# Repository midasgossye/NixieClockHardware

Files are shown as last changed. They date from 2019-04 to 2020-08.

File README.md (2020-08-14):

# NixieClockHardware
6 digit RPi powered Nixie Clock Hardware repository

Software/source code can be found in the following repository: https://github.com/midasgossye/NixieClock/

If you are interested in a having this unique Nixie Clock, but don't want to build it from scratch, we sell these at our tindie store!


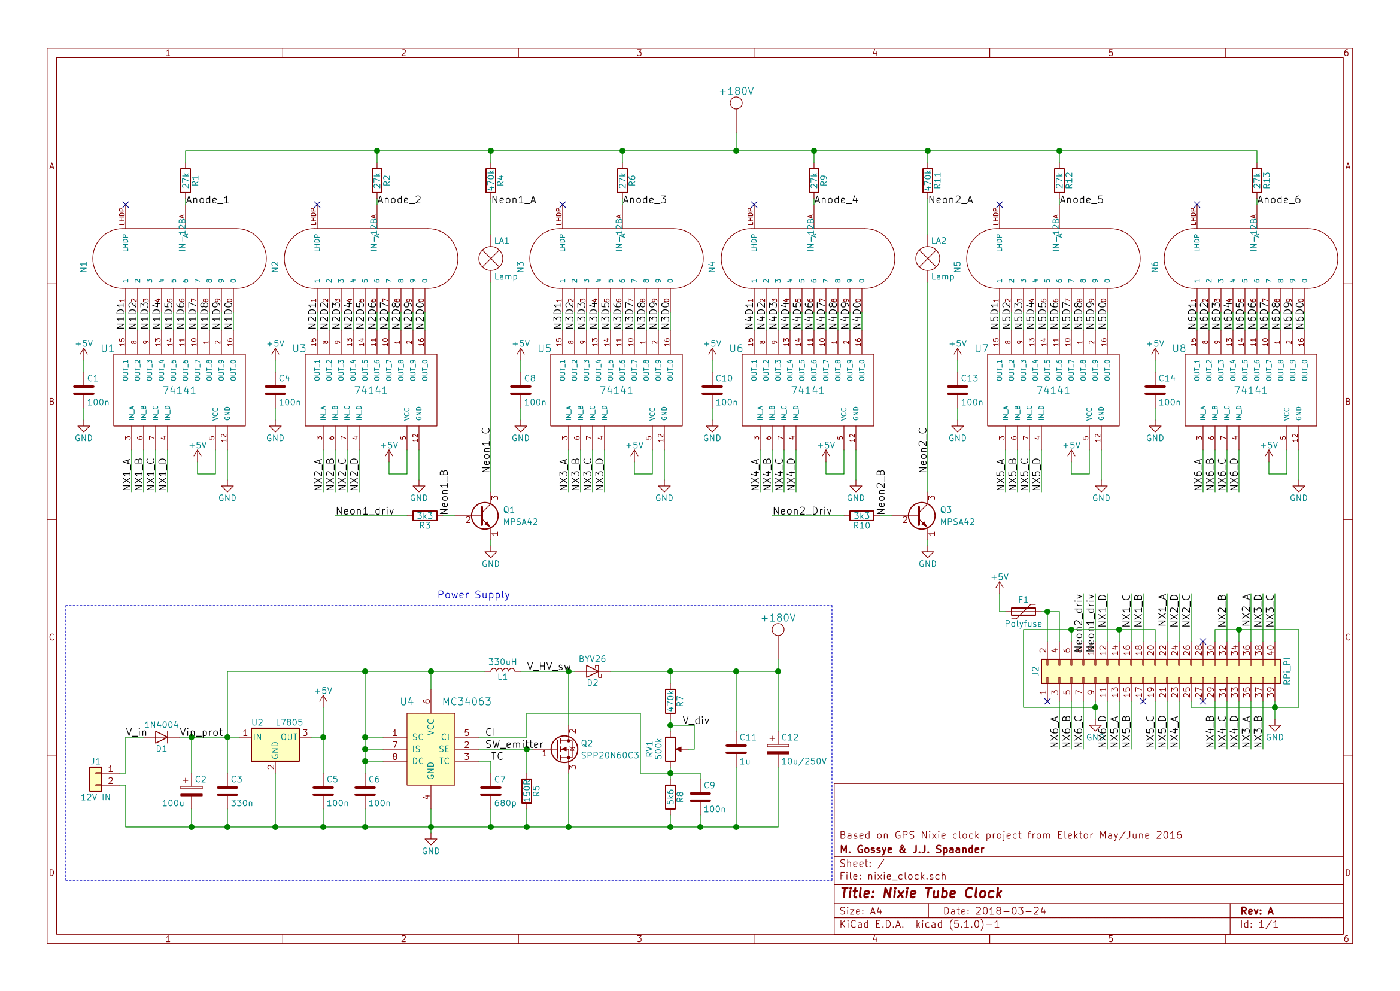
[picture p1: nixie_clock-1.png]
Schematic

Nixie picture

## Authors

* **Midas Gossye** - [Github](https://github.com/midasgossye)
* **Joshua Spaander** - [Github](https://github.com/joshuaspaander)

## Acknowledgments

* This project was inspired by and partly based on the New Precise Nixie Clock from the May 2016 issue of Elektor Magazine [(link)](https://www.elektormagazine.com/magazine/elektor-201605/28960)
* IoT connectivity inspired by EEVBlog Nixie Tube Display Project [(link)](https://www.youtube.com/playlist?list=PLvOlSehNtuHutdg1kZkG7aAYhjoJnk2fc)

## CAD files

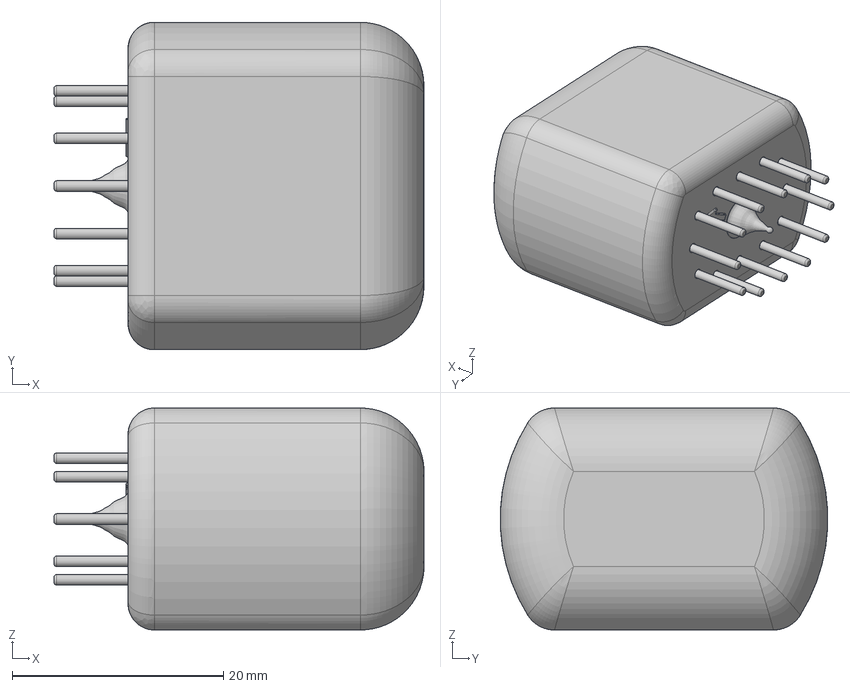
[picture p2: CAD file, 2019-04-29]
IN-12A.stp
35.0 x 31.0 x 21.0 mm

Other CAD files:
nixie_clock.wrl.sldprt
nixie_clock.wrl_0.sldprt

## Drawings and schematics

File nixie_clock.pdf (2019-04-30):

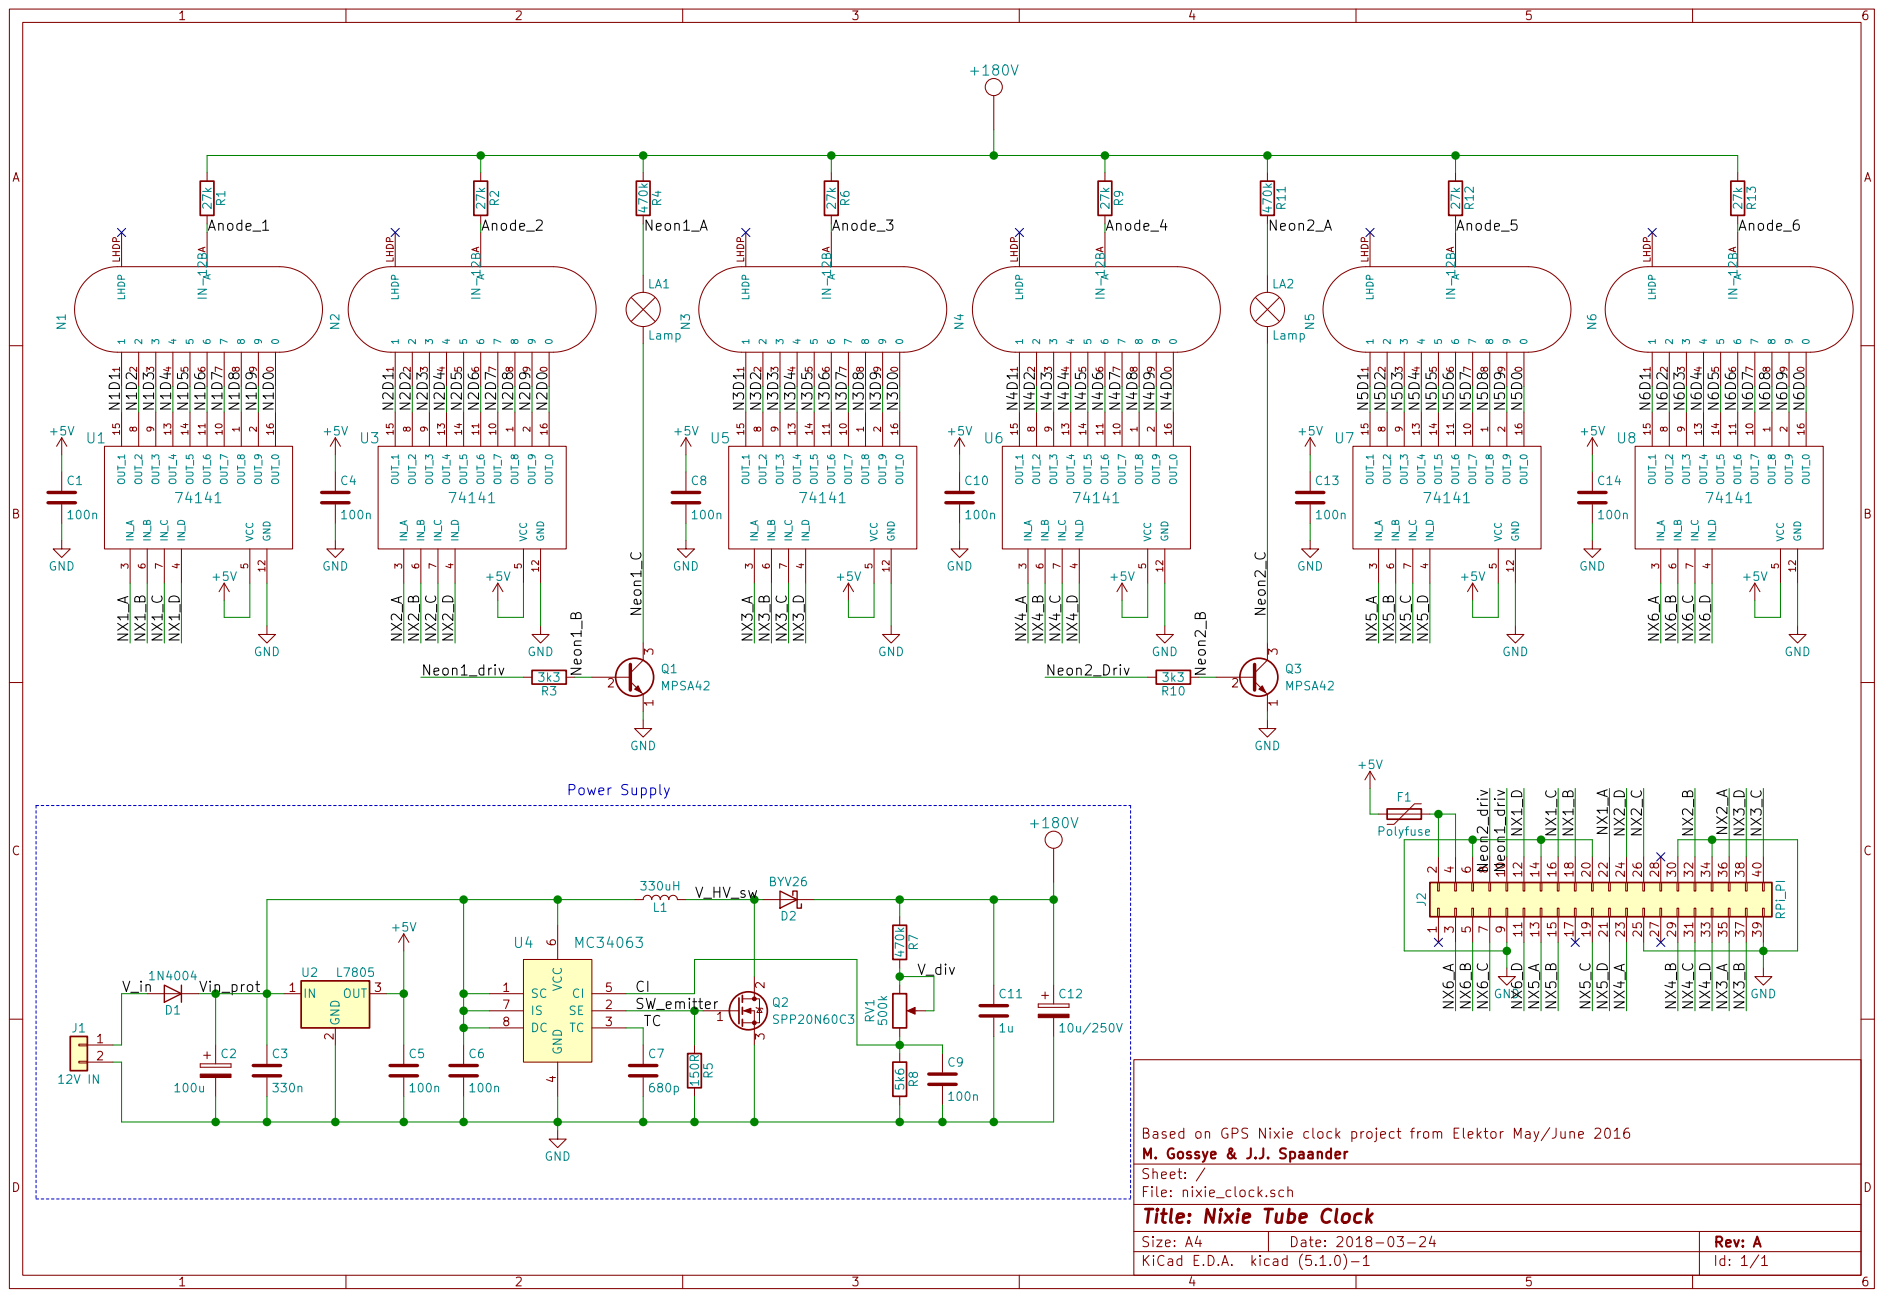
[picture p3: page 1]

Based on GPS Nixie clock project from Elektor May/June 2016
File: nixie_clock.sch Sheet: / M. Gossye & J.J. Spaander

Id: 1/1 Title: Nixie Tube Clock

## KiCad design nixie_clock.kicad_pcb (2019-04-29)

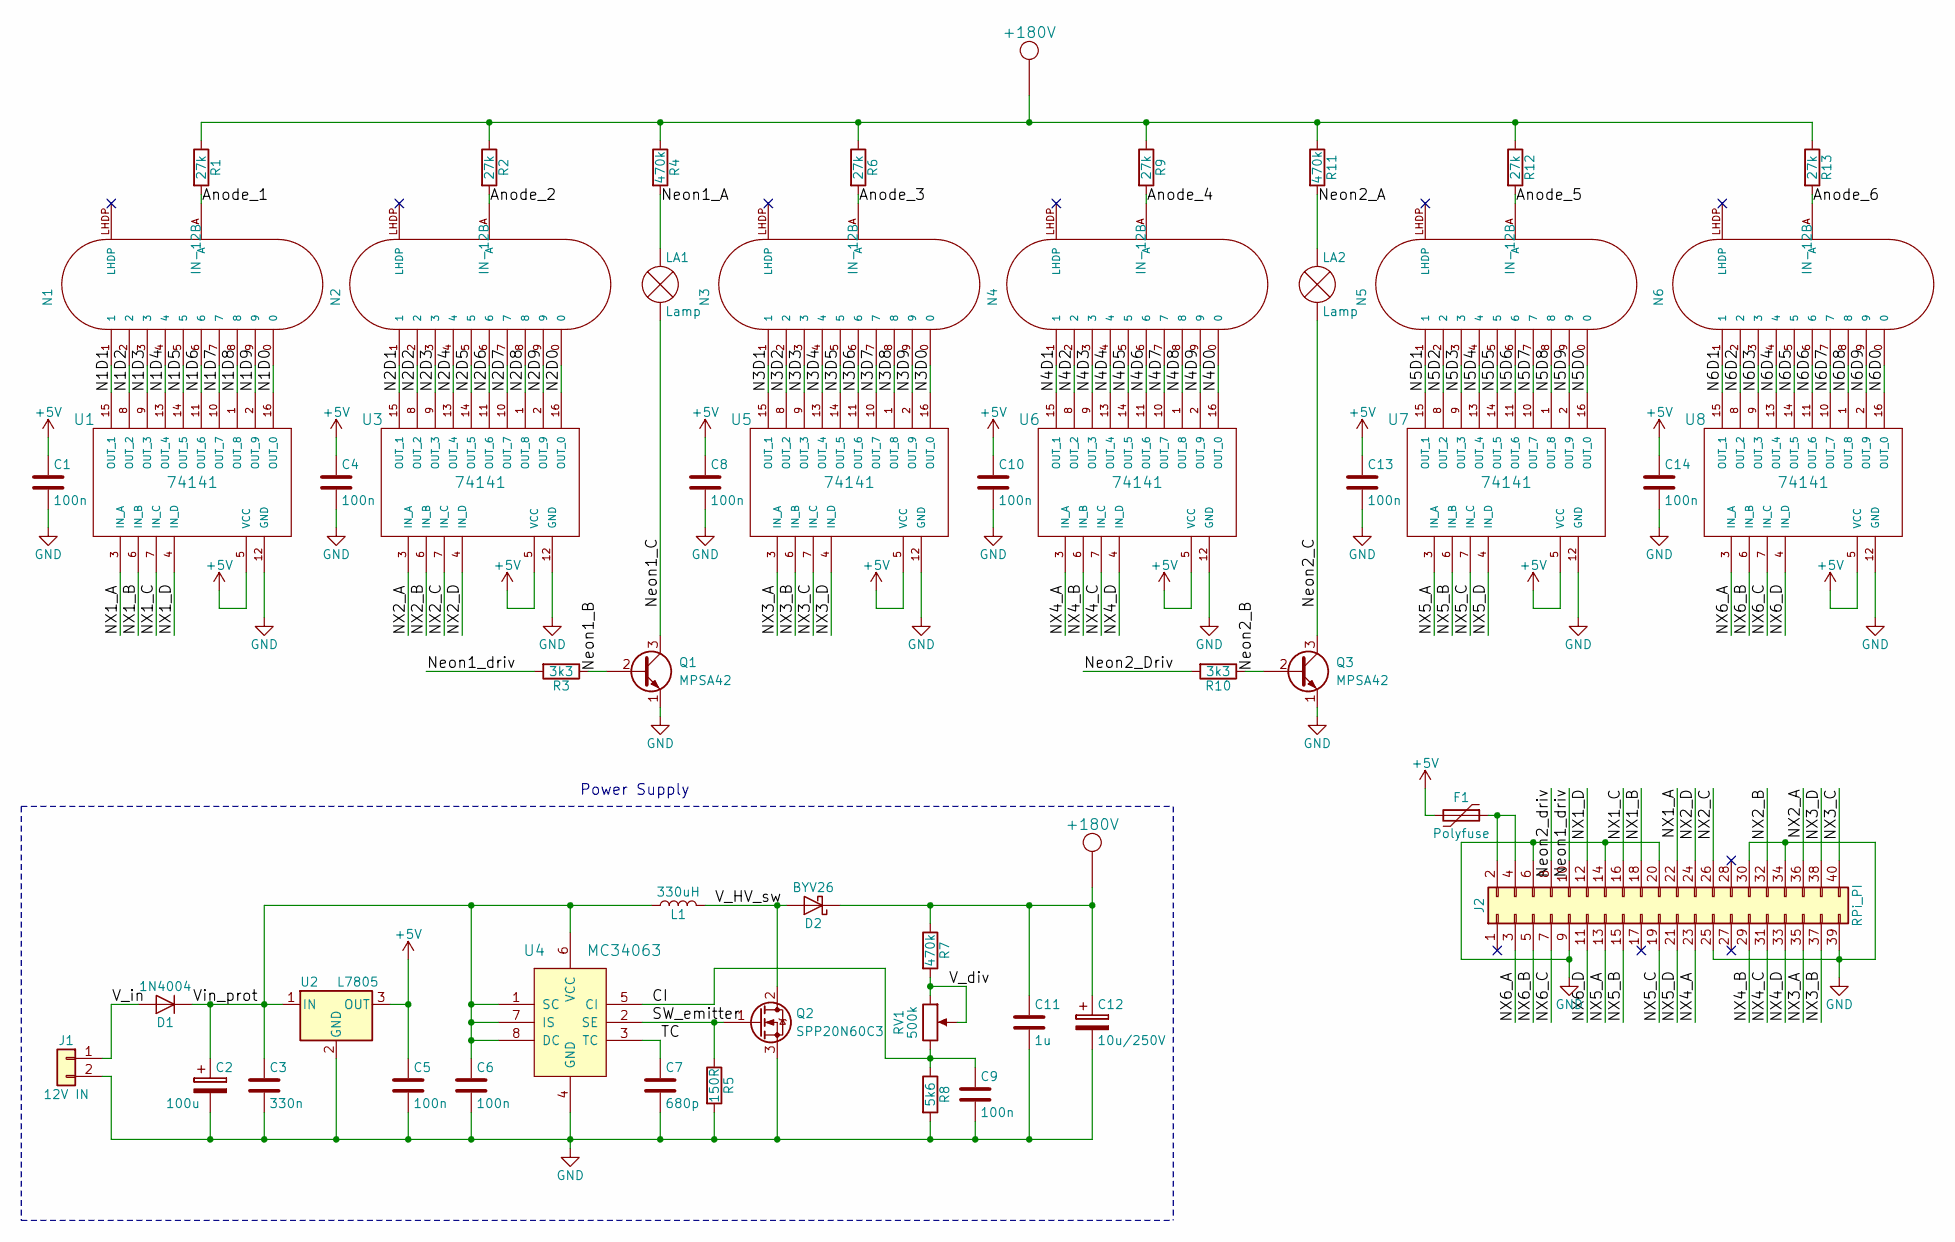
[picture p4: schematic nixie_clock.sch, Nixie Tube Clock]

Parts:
C1, C4, C5, C6, C8, C9, C10, C13, C14: 100n; C_1206_HandSoldering
C2: 100u; CP_Radial_D6.3mm_P2.50mm
C3: 330n; C_1206_HandSoldering
C7: 680p; C_0805_HandSoldering
C11: 1u; C_Rect_L18.0mm_W11.0mm_P15.00mm_FKS3_FKP3
C12: 10u/250V; CP_Radial_D10.0mm_P5.00mm
D1: 1N4004; D_DO-41_SOD81_P10.16mm_Horizontal
D2: BYV26; SOD-57
F1: Polyfuse; R_1206_HandSoldering
J1: 12V IN; BARREL_JACK
J2: RPi_PI; RPi-zero
L1: 330uH; SMDRI127
LA1, LA2: Lamp; Pin_Header_Straight_1x02_Pitch2.54mm
N1, N2, N3, N4, N5, N6: IN-12B; IN-12
Q1, Q3: MPSA42; TO-92_Inline_Narrow_Oval
Q2: SPP20N60C3; TO-220-3_Vertical
R1, R2, R6, R9, R12, R13: 27k; R_Axial_DIN0207_L6.3mm_D2.5mm_P10.16mm_Horizontal
R3, R10: 3k3; R_Axial_DIN0207_L6.3mm_D2.5mm_P10.16mm_Horizontal
R4, R7, R11: 470k; R_Axial_DIN0207_L6.3mm_D2.5mm_P15.24mm_Horizontal
R5: 150R; R_1206_HandSoldering
R8: 5k6; R_Axial_DIN0207_L6.3mm_D2.5mm_P10.16mm_Horizontal
RV1: 500k; 3362P
U1, U3, U5, U6, U7, U8: 74141; DIP-16_W7.62mm_Socket
U2: L7805; TO-220-3_Vertical
U4: MC34063; DIP-8_W7.62mm

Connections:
+5V: C1.1, C4.1, C5.1, C8.1, C10.1, C13.1, C14.1, F1.2, U1.5 (VCC), U2.3 (OUT), U3.5 (VCC), U5.5 (VCC), U6.5 (VCC), U7.5 (VCC), U8.5 (VCC)
+180V: C11.1, C12.1, D2.1 (K), R1.1, R2.1, R4.1, R6.1, R7.1, R9.1, R11.1, R12.1, R13.1
/Anode_1: N1.A, R1.2
/Anode_2: N2.A, R2.2
/Anode_3: N3.A, R6.2
/Anode_4: N4.A, R9.2
/Anode_5: N5.A, R12.2
/Anode_6: N6.A, R13.2
/CI: C9.1, R8.1, RV1.3, U4.5 (CI)
/N1D0: N1.0, U1.16 (OUT_0)
/N1D1: N1.1, U1.15 (OUT_1)
/N1D2: N1.2, U1.8 (OUT_2)
/N1D3: N1.3, U1.9 (OUT_3)
/N1D4: N1.4, U1.13 (OUT_4)
/N1D5: N1.5, U1.14 (OUT_5)
/N1D6: N1.6, U1.11 (OUT_6)
/N1D7: N1.7, U1.10 (OUT_7)
/N1D8: N1.8, U1.1 (OUT_8)
/N1D9: N1.9, U1.2 (OUT_9)
/N2D0: N2.0, U3.16 (OUT_0)
/N2D1: N2.1, U3.15 (OUT_1)
/N2D2: N2.2, U3.8 (OUT_2)
/N2D3: N2.3, U3.9 (OUT_3)
/N2D4: N2.4, U3.13 (OUT_4)
/N2D5: N2.5, U3.14 (OUT_5)
/N2D6: N2.6, U3.11 (OUT_6)
/N2D7: N2.7, U3.10 (OUT_7)
/N2D8: N2.8, U3.1 (OUT_8)
/N2D9: N2.9, U3.2 (OUT_9)
/N3D0: N3.0, U5.16 (OUT_0)
/N3D1: N3.1, U5.15 (OUT_1)
/N3D2: N3.2, U5.8 (OUT_2)
/N3D3: N3.3, U5.9 (OUT_3)
/N3D4: N3.4, U5.13 (OUT_4)
/N3D5: N3.5, U5.14 (OUT_5)
/N3D6: N3.6, U5.11 (OUT_6)
/N3D7: N3.7, U5.10 (OUT_7)
/N3D8: N3.8, U5.1 (OUT_8)
/N3D9: N3.9, U5.2 (OUT_9)
/N4D0: N4.0, U6.16 (OUT_0)
/N4D1: N4.1, U6.15 (OUT_1)
/N4D2: N4.2, U6.8 (OUT_2)
/N4D3: N4.3, U6.9 (OUT_3)
/N4D4: N4.4, U6.13 (OUT_4)
/N4D5: N4.5, U6.14 (OUT_5)
/N4D6: N4.6, U6.11 (OUT_6)
/N4D7: N4.7, U6.10 (OUT_7)
/N4D8: N4.8, U6.1 (OUT_8)
/N4D9: N4.9, U6.2 (OUT_9)
/N5D0: N5.0, U7.16 (OUT_0)
/N5D1: N5.1, U7.15 (OUT_1)
/N5D2: N5.2, U7.8 (OUT_2)
/N5D3: N5.3, U7.9 (OUT_3)
/N5D4: N5.4, U7.13 (OUT_4)
/N5D5: N5.5, U7.14 (OUT_5)
/N5D6: N5.6, U7.11 (OUT_6)
/N5D7: N5.7, U7.10 (OUT_7)
/N5D8: N5.8, U7.1 (OUT_8)
/N5D9: N5.9, U7.2 (OUT_9)
/N6D0: N6.0, U8.16 (OUT_0)
/N6D1: N6.1, U8.15 (OUT_1)
/N6D2: N6.2, U8.8 (OUT_2)
/N6D3: N6.3, U8.9 (OUT_3)
/N6D4: N6.4, U8.13 (OUT_4)
/N6D5: N6.5, U8.14 (OUT_5)
/N6D6: N6.6, U8.11 (OUT_6)
/N6D7: N6.7, U8.10 (OUT_7)
/N6D8: N6.8, U8.1 (OUT_8)
/N6D9: N6.9, U8.2 (OUT_9)
/NX1_A: J2.22, U1.3 (IN_A)
/NX1_B: J2.18, U1.6 (IN_B)
/NX1_C: J2.16, U1.7 (IN_C)
/NX1_D: J2.12, U1.4 (IN_D)
/NX2_A: J2.36, U3.3 (IN_A)
/NX2_B: J2.32, U3.6 (IN_B)
/NX2_C: J2.26, U3.7 (IN_C)
/NX2_D: J2.24, U3.4 (IN_D)
/NX3_A: J2.35, U5.3 (IN_A)
/NX3_B: J2.37, U5.6 (IN_B)
/NX3_C: J2.40, U5.7 (IN_C)
/NX3_D: J2.38, U5.4 (IN_D)
/NX4_A: J2.23, U6.3 (IN_A)
/NX4_B: J2.29, U6.6 (IN_B)
/NX4_C: J2.31, U6.7 (IN_C)
/NX4_D: J2.33, U6.4 (IN_D)
/NX5_A: J2.13, U7.3 (IN_A)
/NX5_B: J2.15, U7.6 (IN_B)
/NX5_C: J2.19, U7.7 (IN_C)
/NX5_D: J2.21, U7.4 (IN_D)
/NX6_A: J2.3, U8.3 (IN_A)
/NX6_B: J2.5, U8.6 (IN_B)
/NX6_C: J2.7, U8.7 (IN_C)
/NX6_D: J2.11, U8.4 (IN_D)
/Neon1_A: LA1.2 (+), R4.2
/Neon1_B: Q1.2 (B), R3.1
/Neon1_C: LA1.1 (-), Q1.3 (C)
/Neon1_driv: J2.10, R3.2
/Neon2_A: LA2.2 (+), R11.2
/Neon2_B: Q3.2 (B), R10.1
/Neon2_C: LA2.1 (-), Q3.3 (C)
/Neon2_Driv: J2.8, R10.2
/SW_emitter: Q2.1 (G), R5.1, U4.2 (SE)
/TC: C7.1, U4.3 (TC)
/V_HV_sw: D2.2 (A), L1.2, Q2.2 (D)
/V_div: R7.2, RV1.1, RV1.2
/V_in: D1.2 (A), J1.1
/Vin_prot: C2.1, C3.1, C6.1, D1.1 (K), L1.1, U2.1 (IN), U4.1 (SC), U4.6 (VCC), U4.7 (IS), U4.8 (DC)
GND: C1.2, C2.2, C3.2, C4.2, C5.2, C6.2, C7.2, C8.2, C9.2, C10.2, C11.2, C12.2, C13.2, C14.2, J1.2, J2.6, J2.9, J2.14, J2.20, J2.25, J2.30, J2.34, J2.39, Q1.1 (E), Q2.3 (S), Q3.1 (E), R5.2, R8.2, U1.12 (GND), U2.2 (GND), U3.12 (GND), U4.4 (GND), U5.12 (GND), U6.12 (GND), U7.12 (GND), U8.12 (GND)
unnamed: F1.1, J2.2, J2.4

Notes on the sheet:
Power Supply

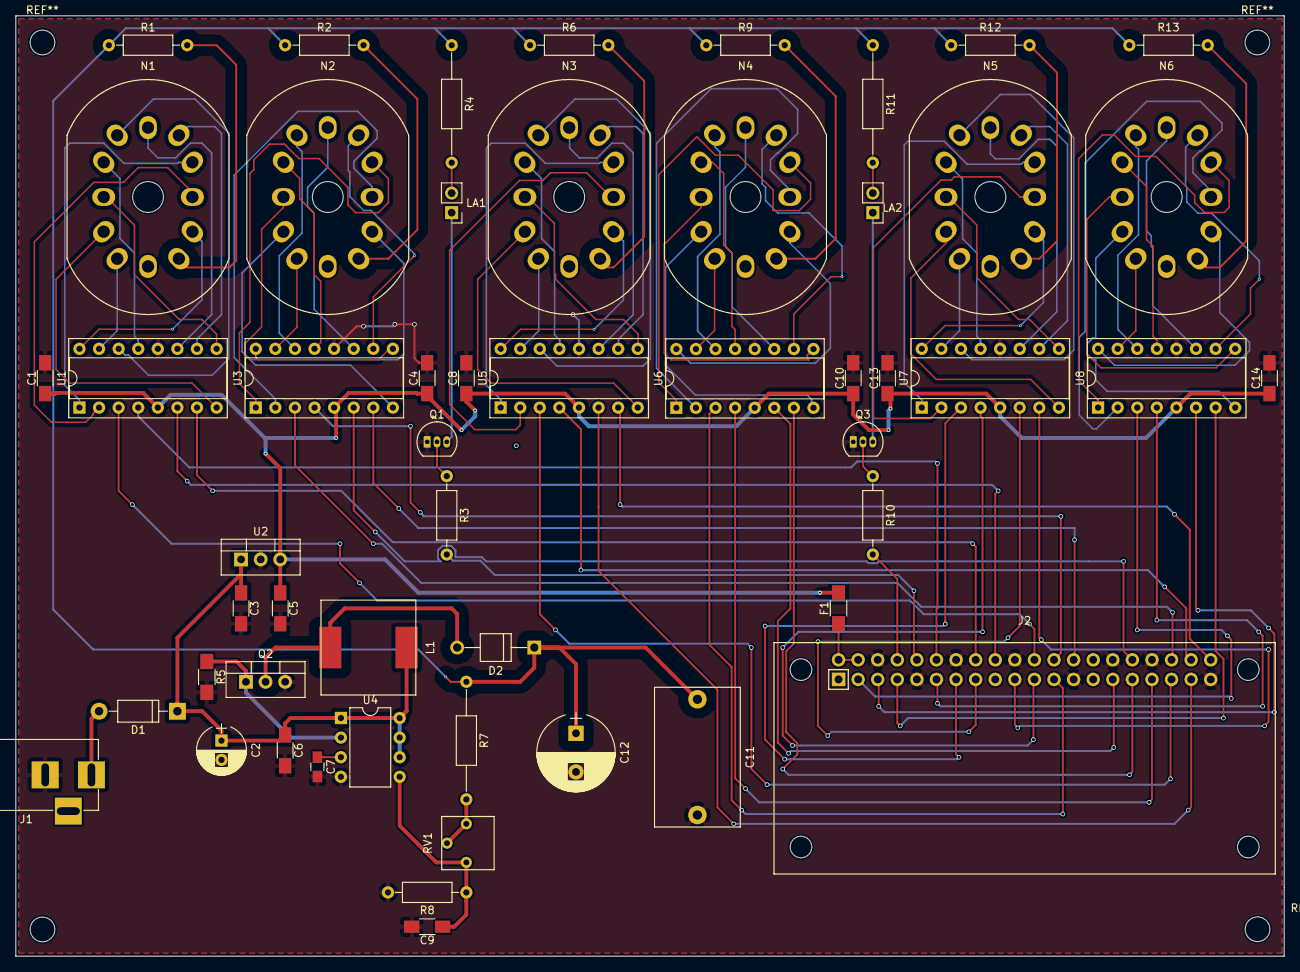
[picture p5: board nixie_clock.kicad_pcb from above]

Board: 2 copper layers, 164.5 x 121.9 mm, 53 parts (0 on the bottom side), 109 nets.
